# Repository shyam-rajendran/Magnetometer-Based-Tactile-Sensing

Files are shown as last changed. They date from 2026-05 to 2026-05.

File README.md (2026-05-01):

# Tactile Sensor

<table align="center">
  <tr>
    <td></td>
    <td></td>
    <td></td>
    <td></td>
  </tr>
</table>

This tactile sensor utilizes magnetometers as a means to detect force vectors acting on the surface. This is done through the combination of magnetometers and a silicone elastomer embedded with neodymium magnets.

This project is heavily inspired by the work of [AnySkin](https://any-skin.github.io/), [ReSkin](https://reskin.dev/) & [Bio-Skin](https://williamalexanda.github.io/Bio-Skin/) and the project is intended to be further developed for magnetic localization, which as of now is still in development. 

The PCB was designed entirely in Altium Designer. I've included the entire Altium project file including the design files, libraries, 3D models, documentations, schematics, gerber.

## Repo Structure
```
1. CAD Files (folder) - Contains the enclosure and mold SolidWorks Part & Assembly files
    a. Mold Designs
        - New Mold Wall 1.SLDPRT
        - New Mold Wall 2.SLDPRT
        - New Mold Assembly.SLDASM
    b. New Enclosure
        - assembly whole thing.SLDASM
        - Bottom enclosure.SLDPRT
        - initial mold assembly.SLDASM
        - Mold Top.SLDPRT
        - Top enclosure.SLDPRT

2. Docs (folder)
   Datasheets of the components used

3. Fabrication Files (folder)
   Gerber file used for manufacturing the PCB

4. Fimrware (folder)
   PlatformIO-VSCode based code environment

5. Libraries (folder) - Includes all the libraries made for PCB design within Altium
    a. 6pin jst.IntLib
    b. PcbLib1.PcbLib
    c. Schlib1.SchLib

6. PCB Design Files (folder)
    a. AnySkin.PcbDoc
    b. AnySkin.PrjPcb
    c. Interface.SchDoc
    d. Schematics.pdf
    e. Sensor Suite.SchDoc

7. Software (folder)
   Python Scripts for force visualization

```

## Sensor ICs used
- MLX90393 (6 Axis Magnetometer) 
- TMP102 (Digital Temperature Sensor)
- TCA9548 (I2C Multiplexer)
- AMS1117 (Low Dropout Voltage Regulator)

## Pinout & Address
The I2C addresses of the ICs are physically set to the specified addresses below but can be changed to alternate I2C address through hardwiring (not recommended).

All the magnetometers share the same I2C address, therefore to prevent address conflict, each magnetometer is connected to the multiplexer and has an individual assigned channel which are selected using bitwise left shift operation. 

_**I2C Peripheral Addresses**_
| Sensor  | I2C Address |
| --- |---|
| MLX90393| 0x0F |
| TMP102  | 0x48 |
| TCA9548 | 0x71 |

\
_**Multiplexer Channel Designation**_
<table>
  <tr>
    <td>

**Multiplexer Channels**
| Channel No | Sensor Address |
|---|---|
| Channel 0  | 0x0F |
| Channel 1  | 0x0F |
| Channel 2  | 0x0F |
| Channel 3  | 0x0F |
| Channel 4  | 0x0F |
| Channel 5  | 0x48 |
| Channel 6  | 0x48 |
| Channel 7  | Unassigned |

  </td>
  <td>

channel desig

  </td>
  </tr>
</table>

## Silicone Elastomer Fabrication
For this project, a two part silicone elastomer is used ([Amazon Link](https://www.amazon.in/RANA-POLYMERS-Silicone-Non-Toxic-Odorless-1/dp/B0F47XKC3K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)) which is mixed in a 1:1 ratio and is then poured into the 3D printed mold design. It roughly takes 3-4 hours for curing and can be easily taken out post curing. 

The elastomer is layered in two parts, such that an array of Neodymium magnets are sandwiched in between.  The Nd magnets are arranged in a 3X3 format such that 5 Nd magnets lie directly above the magnetometer and the remaining 4 Nd magnets lie in the interstitial space between them.

The entire process can be divided into three stages:

1. `First Elastomer Layer` 
    -  The mixture of Part A & B is poured into the mold enclosure upto 3 mm height and is then allowed to cure.
2. `Magnets Arrangement` 
    - Once the initial elastomer layer is cured, the magnets are arranged manually and are forcefully sticked onto the top surface of the first silicone layer using adhesive. 
3. `Second Elastomer Layer`
    - The second elastomer layer is poured on top of the magnets, filling out the entire remaining volume of the mold. Allow it to cure for 3-4 hours and then the mold walls can be removed.

<table align="center">
  <tr>
    <td></td>
    <td></td>
    <td></td>
  </tr>
</table>

After taking out the silicone elastomer, it can be put directly on top of the enclosure and is ready to use! 

\
Author: Shyam Rajendran

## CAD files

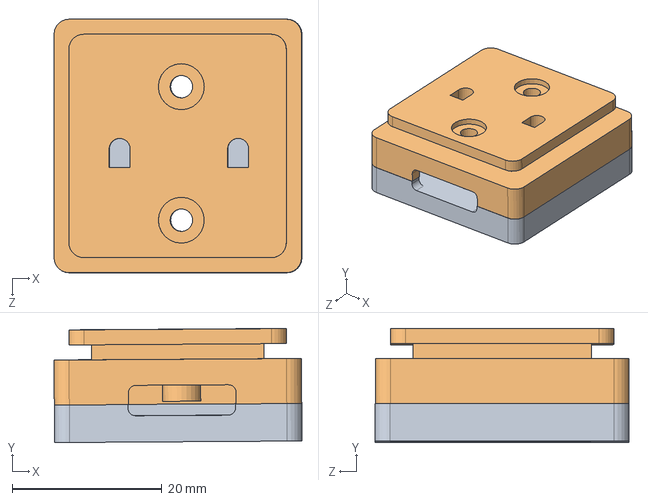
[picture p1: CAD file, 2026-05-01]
CAD Files/new enclosures/assembly whole thing.SLDASM
33.1 x 15.2 x 33.8 mm
Top enclosure
Bottom enclosure

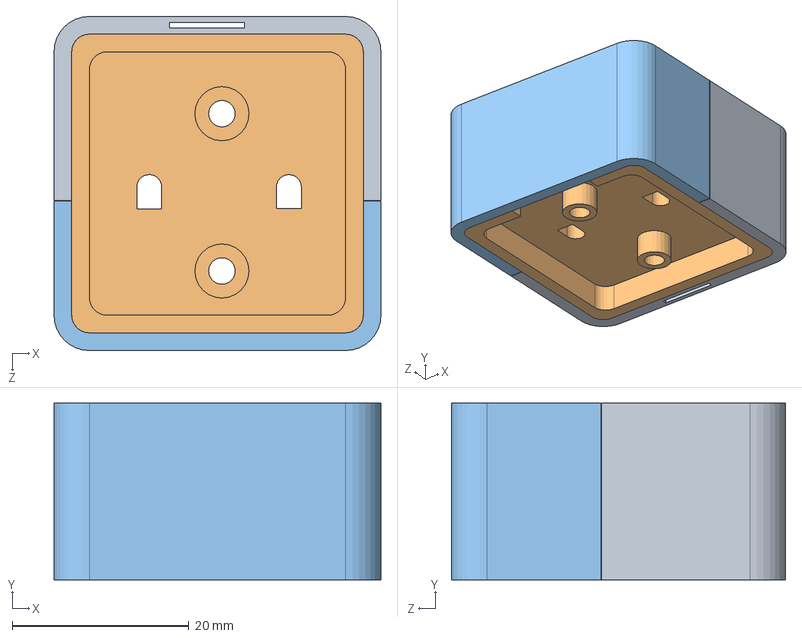
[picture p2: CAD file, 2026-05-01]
CAD Files/mold designs/NEW MOLD ASSEMBLY.SLDASM
37.0 x 20.0 x 37.8 mm
new mold wall 2
Top enclosure
New mold Wall 1

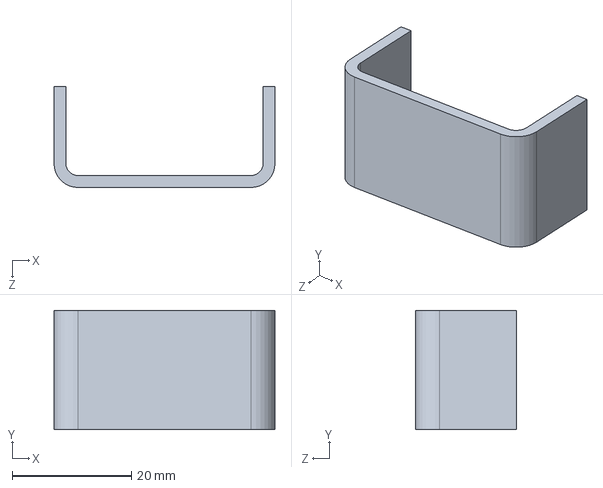
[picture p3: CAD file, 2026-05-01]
CAD Files/mold designs/new mold wall 2.SLDPRT
37.0 x 20.0 x 16.9 mm

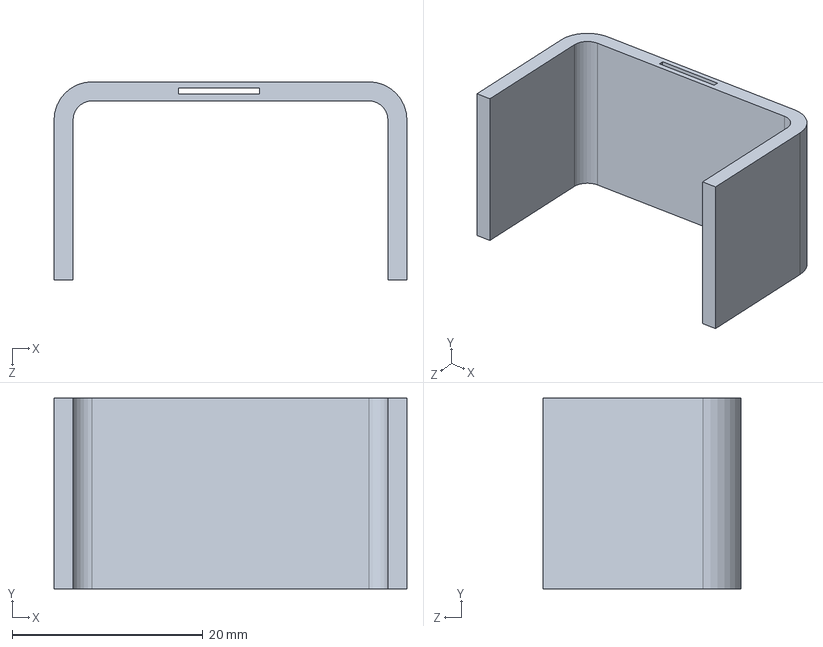
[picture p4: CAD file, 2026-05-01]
CAD Files/mold designs/New mold Wall 1.SLDPRT
37.0 x 20.0 x 20.8 mm

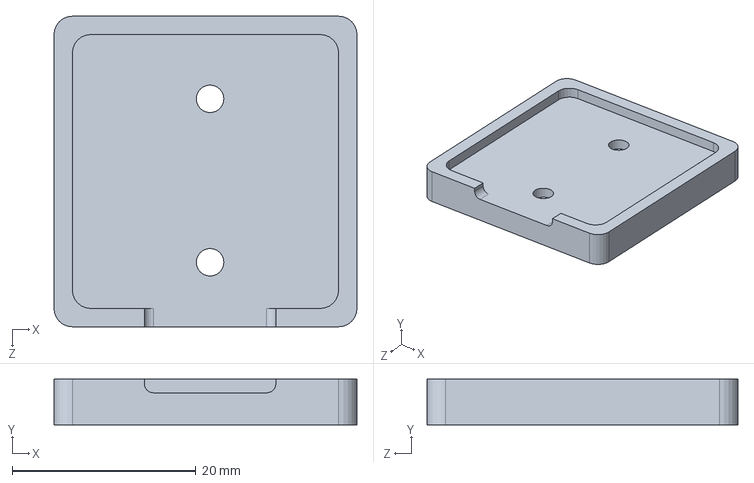
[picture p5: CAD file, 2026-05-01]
CAD Files/new enclosures/Bottom enclosure.SLDPRT
33.0 x 5.00 x 33.8 mm

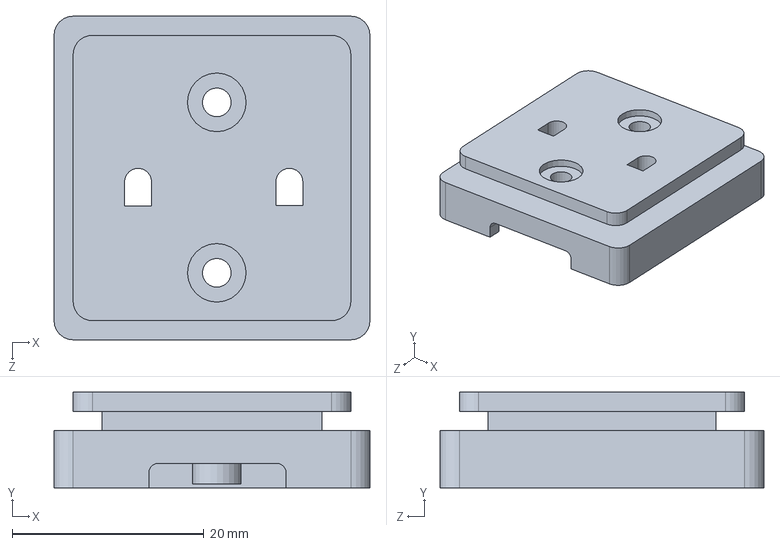
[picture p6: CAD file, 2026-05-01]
CAD Files/new enclosures/Top enclosure.SLDPRT
33.0 x 10.0 x 33.8 mm

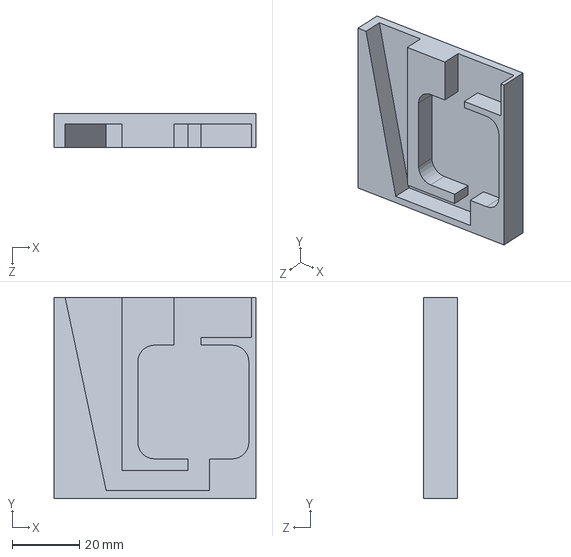
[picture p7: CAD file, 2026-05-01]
CAD Files/new enclosures/Mold Top.SLDPRT
60.0 x 59.8 x 10.0 mm

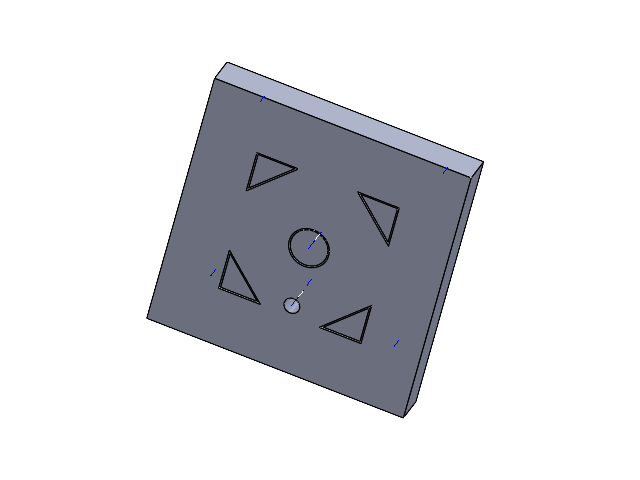
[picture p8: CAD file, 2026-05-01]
CAD Files/new enclosures/initial mold assembly.SLDASM
Mold shape
mold casing alternate bottom

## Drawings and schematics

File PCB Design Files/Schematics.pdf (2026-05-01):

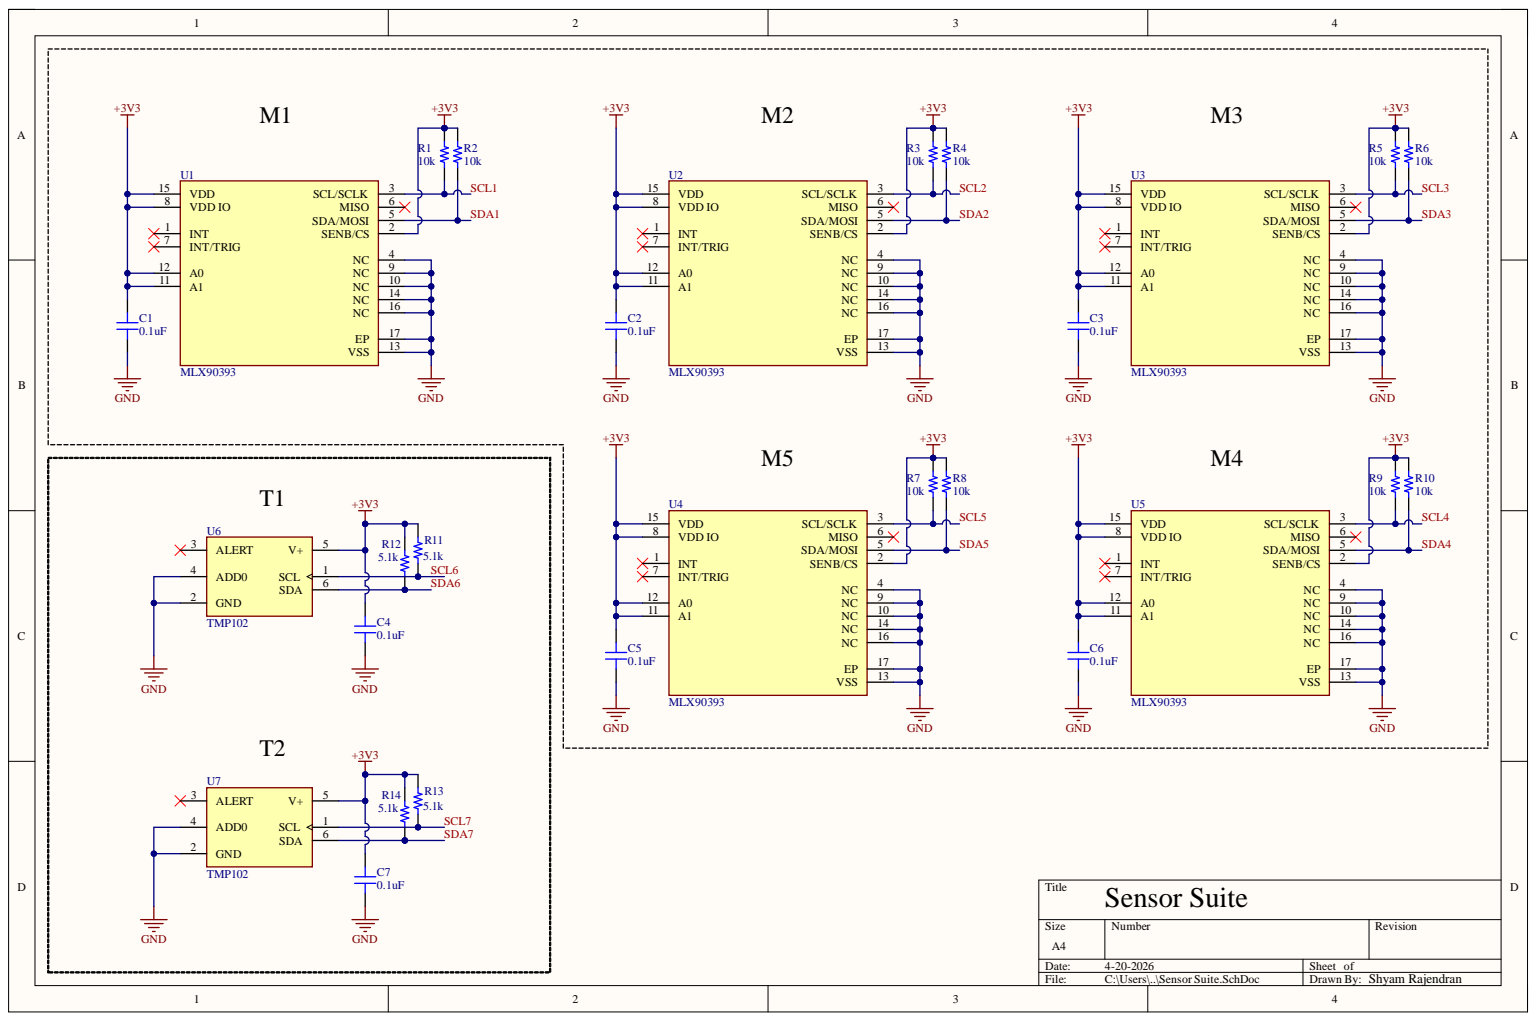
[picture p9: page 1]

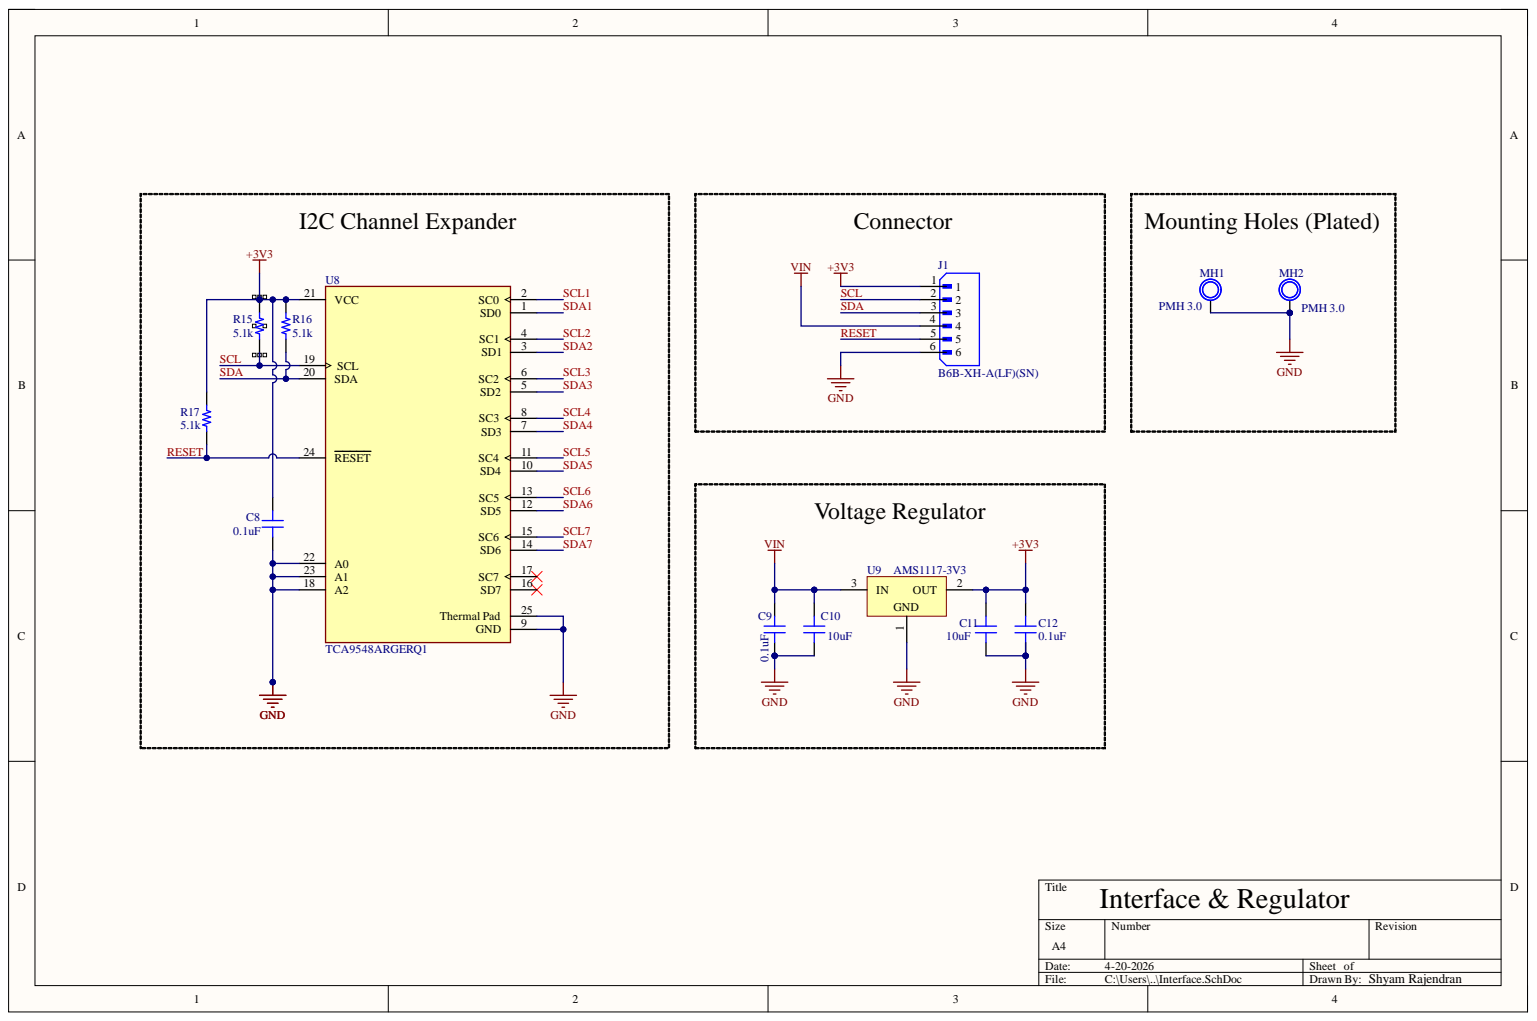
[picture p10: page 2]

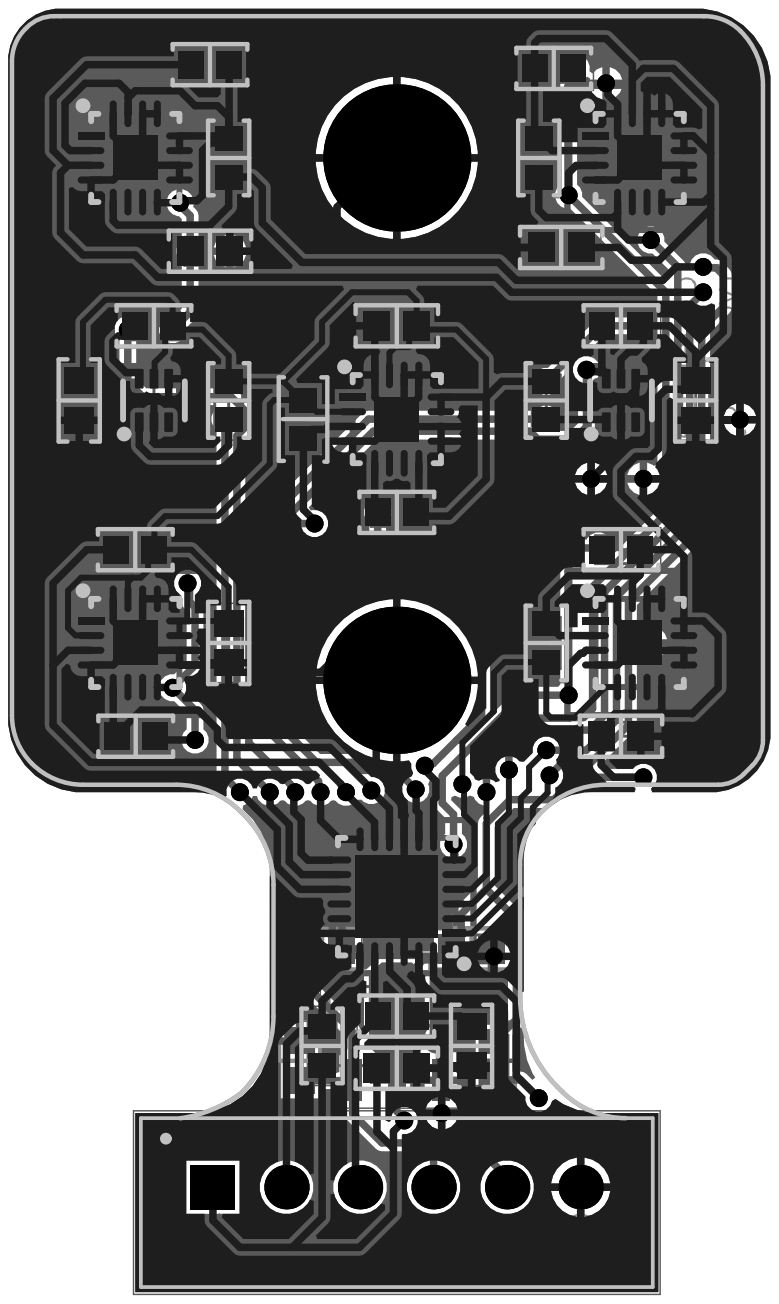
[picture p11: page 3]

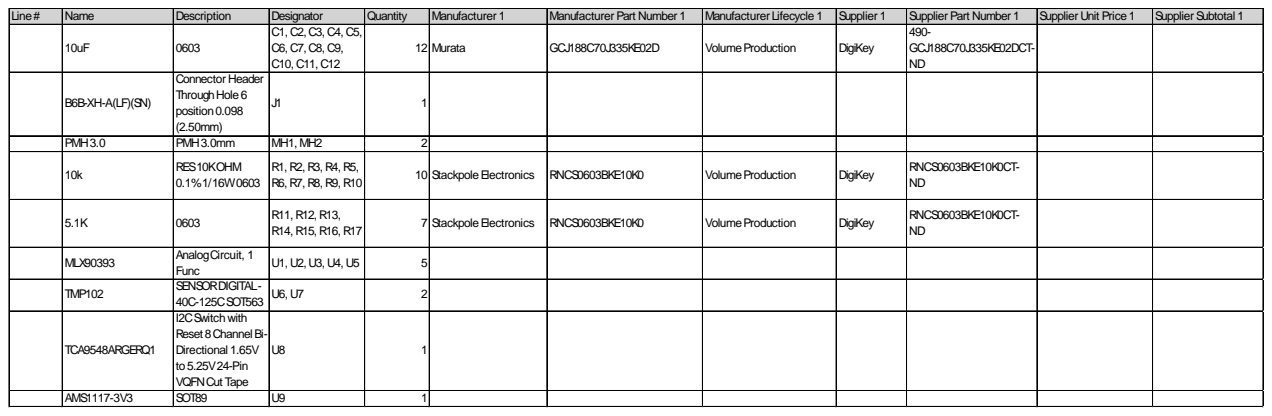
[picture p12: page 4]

Line# | Name | Description | Designator | Quantity | Manufacturer 1 | Manufacturer Part Number 1 | Manufacturer Lifecycle 1 | Supplier 1 | Supplier Part Number 1 | Supplier Unit Price 1 | Supplier Subtotal 1

10uF | 0603 | C1, C2, C3, C4, C5, C6, C7, C8, C9, C10, C11, C12 | 12 | Murata | GCJ188C70J335KE02D | VolumeProduction | DigiKey | 490-GCJ188C70J335KE02DCT-ND

B6B-XH-A(LF)(SN) | Connector Header ThroughHole6 position0.098 (2.50mm) | J1 | 1

PMH3.0 | PMH3.0mm | MH1, MH2 | 2

10k | RES10KOHM 0.1%1/16W0603 | R1, R2, R3, R4, R5, R6, R7, R8, R9, R10 | 10 | StackpoleElectronics | RNCS0603BKE10K0 | VolumeProduction | DigiKey | RNCS0603BKE10K0CT-ND

5.1K | 0603 | R11, R12, R13, R14, R15, R16, R17 | 7 | StackpoleElectronics | RNCS0603BKE10K0 | VolumeProduction | DigiKey | RNCS0603BKE10K0CT-ND

MLX90393 | AnalogCircuit, 1 Func | U1, U2, U3, U4, U5 | 5

TMP102 | SENSORDIGITAL-40C-125CSOT563 | U6, U7 | 2

TCA9548ARGERQ1 | I2CSwitch with Reset 8Channel Bi-Directional 1.65V to5.25V24-Pin VQFNCut Tape | U8 | 1

AMS1117-3V3 | SOT89 | U9 | 1

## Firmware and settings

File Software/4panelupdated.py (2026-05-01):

import sys
import numpy as np
import serial
import time
from multiprocessing import Process, Array, Value, Event
import ctypes as ct
from scipy.interpolate import griddata
from matplotlib.backends.backend_qt5agg import FigureCanvasQTAgg as FigureCanvas
from matplotlib.figure import Figure
from mpl_toolkits.mplot3d import Axes3D  # noqa: F401

from PyQt5 import QtWidgets, QtCore, QtGui
import pyqtgraph as pg

# ── Config ───────────────────────────────────────────────────────────────
PORT = 'COM5'
BAUD = 250000
NUM_SENSORS = 5

# ── Sensor layout (meters) ───────────────────────────────────────────────
SENSOR_POS = np.array([
    [0.000, 0.018],   # ch0 top-left
    [0.018, 0.018],   # ch1 top-right
    [0.018, 0.000],   # ch2 bottom-right
    [0.009, 0.009],   # ch3 center
    [0.000, 0.000],   # ch4 bottom-left
])

# ── TMP102 physical positions (meters) — adjust to match your PCB ────────
TEMP_POS = np.array([
    [0.004, 0.009],   # T1 (ch5) — left side
    [0.014, 0.009],   # T2 (ch6) — right side
])

# ── Temperature safety thresholds (°C) ──────────────────────────────────
TEMP_SAFE    = 36.0
TEMP_CAUTION = 43.0
TEMP_DANGER  = 48.0

# ── Per-sensor chip orientation (radians, CCW from +X) ───────────────────
CHIP_ROTATIONS = np.zeros(NUM_SENSORS)

# ── Per-sensor circle+arrow panel layout (pixels in 220x220 canvas) ──────
CHIP_PX = np.array([
    [ 55,  55],   # ch0 top-left
    [165,  55],   # ch1 top-right
    [165, 165],   # ch2 bottom-right
    [110, 110],   # ch3 center
    [ 55, 165],   # ch4 bottom-left
], dtype=float)

CANVAS_SIZE = 220
BZ_SCALE    = 2.0
XY_SCALE    = 2.0

# ── Adaptive EMA baseline config ─────────────────────────────────────────
EMA_ALPHA          = 0.02
ACTIVITY_THRESHOLD = 3.0
DEAD_ZONE          = 5.0

# ── Heatmap / 3D grid ────────────────────────────────────────────────────
GRID_RES = 50
xi = np.linspace(0, 0.018, GRID_RES)
yi = np.linspace(0, 0.018, GRID_RES)
XI, YI = np.meshgrid(xi, yi)

HMAP_RES = 100
xi_h = np.linspace(0, 0.018, HMAP_RES)
yi_h = np.linspace(0, 0.018, HMAP_RES)
XI_H, YI_H = np.meshgrid(xi_h, yi_h)


# ── Parse ─────────────────────────────────────────────────────────────────
def parse_line(line):
    data  = np.zeros((NUM_SENSORS, 3))
    temps = [None, None]
    try:
        tokens = line.strip().split(',')
        i = 0
        while i < len(tokens):
            tok = tokens[i].strip()
            if tok.startswith('#'):
                ch = int(tok[1:])
                if ch < NUM_SENSORS and i + 3 < len(tokens):
                    data[ch] = [float(tokens[i+1]), float(tokens[i+2]), float(tokens[i+3])]
                i += 4
            elif tok == 'T1':
                temps[0] = float(tokens[i+1])
                i += 2
            elif tok == 'T2':
                temps[1] = float(tokens[i+1])
                i += 2
            else:
                i += 1
        return data, temps
    except Exception:
        return None, [None, None]


# ── Background serial reader process ─────────────────────────────────────
class SensorProcess(Process):
    def __init__(self):
        super().__init__(daemon=True)
        self._raw       = Array(ct.c_float, NUM_SENSORS * 3)
        self._baseline  = Array(ct.c_float, NUM_SENSORS * 3)
        self._counter   = Value(ct.c_uint64, 0)
        self._ready     = Event()
        self._recal_req = Event()
        self._temps     = Array(ct.c_float, 2)
        self._temps[0]  = -999.0
        self._temps[1]  = -999.0

        self.CONTACT_THRESHOLD = 3.5

    @property
    def counter(self):
        return self._counter.value

    @property
    def latest(self):
        raw      = np.array(self._raw[:]).reshape(NUM_SENSORS, 3)
        baseline = np.array(self._baseline[:]).reshape(NUM_SENSORS, 3)
        delta    = raw - baseline
        mean     = np.mean(delta, axis=0)
        delta    = delta - mean
        delta[np.abs(delta) < DEAD_ZONE] = 0.0
        return delta

    @property
    def temperatures(self):
        return list(self._temps)

    def request_recalibrate(self):
        self._recal_req.set()

    def wait_until_ready(self, timeout=20.0):
        return self._ready.wait(timeout=timeout)

    def _read_sample(self, ser):
        if ser.in_waiting > 4000:
            ser.reset_input_buffer()
            ser.readline()
        raw = ser.readline().decode('utf-8', errors='ignore')
        return parse_line(raw)

    def _hard_baseline(self, ser, n=30):
        print("[SensorProcess] Capturing baseline — keep sensor still...")
        samples = []
        while len(samples) < n:
            data, _ = self._read_sample(ser)
            if data is not None:
                samples.append(data)
        baseline = np.mean(samples, axis=0)
        self._baseline[:] = baseline.flatten().tolist()
        print("[SensorProcess] Baseline done.")
        return baseline.copy()

    def run(self):
        ser = serial.Serial(PORT, BAUD, timeout=1)
        print(f"[SensorProcess] Connected to {PORT}")
        time.sleep(2.0)
        ser.reset_input_buffer()

        baseline = self._hard_baseline(ser)
        self._ready.set()

        while True:
            if self._recal_req.is_set():
                self._recal_req.clear()
                baseline = self._hard_baseline(ser)

            data, temps = self._read_sample(ser)
            if data is None:
                continue

            self._raw[:] = data.flatten().tolist()
            self._counter.value += 1

            if temps[0] is not None:
                self._temps[0] = temps[0]
            if temps[1] is not None:
                self._temps[1] = temps[1]

            delta = data - baseline
            mean  = np.mean(delta, axis=0)
            delta_cm_removed  = delta - mean
            spatial_variation = np.std(delta_cm_removed, axis=0)
            variation_norm    = np.linalg.norm(spatial_variation)
            is_contact        = variation_norm > self.CONTACT_THRESHOLD

            if not is_contact:
                baseline = (1.0 - EMA_ALPHA) * baseline + EMA_ALPHA * data
                self._baseline[:] = baseline.flatten().tolist()


# ── Per-sensor circle+arrow widget ───────────────────────────────────────
class SensorDotWidget(QtWidgets.QWidget):
    def __init__(self, parent=None):
        super().__init__(parent)
        self.setMinimumSize(300, 300)
        self.setSizePolicy(QtWidgets.QSizePolicy.Expanding, QtWidgets.QSizePolicy.Expanding)
        self._data = np.zeros((NUM_SENSORS, 3))

        self._rot = []
        for angle in CHIP_ROTATIONS:
            c, s = np.cos(angle), np.sin(angle)
            self._rot.append(np.array([[c, -s], [s, c]]))

    def update_data(self, data):
        self._data = data
        self.update()

    def paintEvent(self, event):
        painter = QtGui.QPainter(self)
        painter.setRenderHint(QtGui.QPainter.Antialiasing)
        painter.fillRect(self.rect(), QtGui.QColor('#1a1a2e'))

        side     = min(self.width(), self.height())
        x_offset = (self.width()  - side) / 2.0
        y_offset = (self.height() - side) / 2.0
        scale    = side / CANVAS_SIZE
        painter.translate(x_offset, y_offset)
        painter.scale(scale, scale)

        painter.setPen(QtGui.QPen(QtGui.QColor(80, 80, 120), 1))
        for px in CHIP_PX:
            painter.drawEllipse(int(px[0]) - 2, int(px[1]) - 2, 4, 4)

        for i, px in enumerate(CHIP_PX):
            bx, by, bz = self._data[i]
            radius = max(int(abs(bz) / BZ_SCALE), 1)
            cx, cy = int(px[0]), int(px[1])

            if bz >= 0:
                painter.setBrush(QtGui.QBrush(QtGui.QColor(220, 60, 60)))
                painter.setPen(QtGui.QPen(QtGui.QColor(220, 60, 60)))
            else:
                painter.setBrush(QtGui.QBrush(QtCore.Qt.NoBrush))
                painter.setPen(QtGui.QPen(QtGui.QColor(220, 60, 60), 2))
            painter.drawEllipse(cx - radius, cy - radius, radius * 2, radius * 2)

            xy_raw = np.array([bx, -by])
            xy_rot = self._rot[i] @ xy_raw
            ax = cx + xy_rot[0] / XY_SCALE
            ay = cy + xy_rot[1] / XY_SCALE

            painter.setPen(QtGui.QPen(QtGui.QColor(46, 204, 113), 2))
            painter.drawLine(cx, cy, int(ax), int(ay))

            length = np.hypot(xy_rot[0], xy_rot[1]) / XY_SCALE
            if length > 3:
                angle = np.arctan2(xy_rot[1], xy_rot[0])
                head  = 6
                for side in [0.4, -0.4]:
                    hx = ax - head * np.cos(angle + side)
                    hy = ay - head * np.sin(angle + side)
                    painter.drawLine(int(ax), int(ay), int(hx), int(hy))

            painter.setPen(QtGui.QPen(QtGui.QColor(200, 200, 200)))
            painter.drawText(cx + radius + 3, cy - radius, f"CH{i}")

        painter.end()


# ── 3D surface widget ─────────────────────────────────────────────────────
class MatplotlibSurfaceWidget(FigureCanvas):
    def __init__(self, parent=None):
        self.figure = Figure(facecolor='#1a1a2e')
        super().__init__(self.figure)
        if parent is not None:
            self.setParent(parent)

        self.setMinimumSize(300, 300)
        self.setSizePolicy(QtWidgets.QSizePolicy.Expanding, QtWidgets.QSizePolicy.Expanding)

        self.ax = self.figure.add_subplot(111, projection='3d')
        self.ax.set_facecolor('#1a1a2e')
        self.ax.view_init(elev=35, azim=-135)
        self.figure.subplots_adjust(left=0.02, right=0.98, bottom=0.05, top=0.95)

        self._surface       = None
        self._sensor_points = None
        self._configure_axes()
        self.update_surface(np.zeros(NUM_SENSORS))

    def _configure_axes(self):
        self.ax.set_title("3D Force Surface (Bz)", color='white', pad=12)
        self.ax.set_xlabel("X (mm)", color='white', labelpad=8)
        self.ax.set_ylabel("Y (mm)", color='white', labelpad=8)
        self.ax.set_zlabel("Bz (uT)", color='white', labelpad=6)
        self.ax.set_xlim(0, 18)
        self.ax.set_ylim(0, 18)
        self.ax.set_zlim(-100, 0)
        self.ax.tick_params(colors='white')
        self.ax.xaxis.pane.set_facecolor((0.10, 0.10, 0.18, 1.0))
        self.ax.yaxis.pane.set_facecolor((0.10, 0.10, 0.18, 1.0))
        self.ax.zaxis.pane.set_facecolor((0.10, 0.10, 0.18, 1.0))

    def update_surface(self, bz_sensors):
        zi = griddata(SENSOR_POS, bz_sensors, (XI_H, YI_H), method='cubic', fill_value=0)
        zi = np.clip(zi, 0, None)
        zi = -zi   # invert so touch pushes DOWN

        if self._surface is not None:
            self._surface.remove()
        if self._sensor_points is not None:
            self._sensor_points.remove()

        x_mm = XI_H * 1000.0
        y_mm = YI_H * 1000.0
        z_uT = zi
        vmax = max(float(np.max(np.abs(z_uT))), 1.0)

        self.ax.set_zlim(-max(vmax * 1.1, 10.0), 0)
        self._surface = self.ax.plot_surface(
            x_mm, y_mm, z_uT,
            cmap='turbo_r',
            linewidth=0,
            antialiased=True,
            vmin=-max(vmax, 10.0),
            vmax=0,
        )
        self._sensor_points = self.ax.scatter(
            SENSOR_POS[:, 0] * 1000.0,
            SENSOR_POS[:, 1] * 1000.0,
            -np.clip(bz_sensors, 0, None),
            c='white', s=18, depthshade=False,
        )
        self.draw_idle()


# ── Temperature heatmap widget ────────────────────────────────────────────
class TempHeatmapWidget(pg.GraphicsLayoutWidget):
    def __init__(self, parent=None):
        super().__init__(parent)
        self.setMinimumSize(300, 300)

        self.plot = self.addPlot(title="Temperature Heatmap (°C)")
        self.plot.setLabel('left', 'Y (mm)')
        self.plot.setLabel('bottom', 'X (mm)')
        self.plot.setAspectLocked(True)

        self.img = pg.ImageItem()
        self.plot.addItem(self.img)
        self.img.setRect(pg.QtCore.QRectF(0, 0, 18, 18))

        # Blue (cold) → green (safe) → yellow (caution) → red (danger)
        # Mapped across 20–50 °C range
        colors = [
            (0,   80,  200),   # cold blue   ~20°C
            (0,   200, 100),   # safe green  ~36°C
            (255, 200, 0  ),   # caution     ~43°C
            (220, 40,  40 ),   # danger red  ~48°C+
        ]
        # Normalise threshold positions to [0,1] over 20–50°C
        TMIN, TMAX = 20.0, 50.0
        pos = np.array([
            0.0,
            (TEMP_SAFE    - TMIN) / (TMAX - TMIN),
            (TEMP_CAUTION - TMIN) / (TMAX - TMIN),
            1.0,
        ])
        cmap = pg.ColorMap(pos=pos, color=colors)
        self.colorbar = pg.ColorBarItem(
            values=(TMIN, TMAX), colorMap=cmap, label='°C'
        )
        self.colorbar.setImageItem(self.img, insert_in=self.plot)

        # Sensor position markers (triangles)
        temp_mm = TEMP_POS * 1000
        self.plot.plot(
            temp_mm[:, 0], temp_mm[:, 1],
            pen=None, symbol='t', symbolSize=12,
            symbolBrush='w', symbolPen='w'
        )

        # Readout labels for T1 and T2
        self._t1_label = pg.TextItem("T1: --.-°C", color='white', anchor=(0, 1))
        self._t2_label = pg.TextItem("T2: --.-°C", color='white', anchor=(1, 1))
        self._t1_label.setPos(0,   18)
        self._t2_label.setPos(18,  18)
        self.plot.addItem(self._t1_label)
        self.plot.addItem(self._t2_label)

        self._last_temps = [25.0, 25.0]
        self.TMIN = TMIN
        self.TMAX = TMAX

    def _temp_color(self, t):
        """Return a hex color string for a temperature value."""
        if t < TEMP_SAFE:
            return '#2ecc71'
        elif t < TEMP_CAUTION:
            return '#f39c12'
        else:
            return '#e74c3c'

    def update_temps(self, temps):
        t = [
            temps[i] if (temps[i] is not None and temps[i] > -900)
            else self._last_temps[i]
            for i in range(2)
        ]
        self._last_temps = t

        # Interpolate temperature across full 18×18 mm grid
        zi = griddata(TEMP_POS, np.array(t), (XI_H, YI_H),
                      method='linear', fill_value=float(np.mean(t)))

        # Normalise to [0, 1] for the colormap (20–50°C)
        zi_norm = (zi - self.TMIN) / (self.TMAX - self.TMIN)
        zi_norm = np.clip(zi_norm, 0, 1)

        self.img.setImage(zi_norm.T)
        self.colorbar.setLevels((self.TMIN, self.TMAX))

        # Update readout text with safety colour
        self._t1_label.setText(f"T1: {t[0]:.1f}°C")
        self._t2_label.setText(f"T2: {t[1]:.1f}°C")
        self._t1_label.setColor(self._temp_color(t[0]))
        self._t2_label.setColor(self._temp_color(t[1]))


# ── Main window ───────────────────────────────────────────────────────────
class Visualizer(QtWidgets.QMainWindow):
    def __init__(self, sensor: SensorProcess):
        super().__init__()
        self.sensor        = sensor
        self._last_counter = -1

        self.setWindowTitle("Tactile Sensor Visualizer  |  B = recalibrate baseline")
        self.resize(1200, 900)

        pg.setConfigOption('background', '#1a1a2e')
        pg.setConfigOption('foreground', 'w')

        central = QtWidgets.QWidget()
        self.setCentralWidget(central)
        layout = QtWidgets.QGridLayout(central)
        layout.setSpacing(10)
        layout.setContentsMargins(10, 10, 10, 10)
        layout.setRowStretch(0, 1)
        layout.setRowStretch(1, 1)
        layout.setColumnStretch(0, 1)
        layout.setColumnStretch(1, 1)

        # ── Panel 0,0: Bz Heatmap ────────────────────────────────────────
        self.heatmap_widget = pg.GraphicsLayoutWidget()
        layout.addWidget(self.heatmap_widget, 0, 0)

        self.heat_plot = self.heatmap_widget.addPlot(title="Bz Heatmap")
        self.heat_plot.setLabel('left', 'Y (mm)')
        self.heat_plot.setLabel('bottom', 'X (mm)')
        self.heat_plot.setAspectLocked(True)

        self.img_item = pg.ImageItem()
        self.heat_plot.addItem(self.img_item)
        self.img_item.setRect(pg.QtCore.QRectF(0, 0, 18, 18))

        colormap = pg.colormap.get('RdBu_r', source='matplotlib')
        self.colorbar = pg.ColorBarItem(values=(-100, 100), colorMap=colormap, label='Bz (uT)')
        self.colorbar.setImageItem(self.img_item, insert_in=self.heat_plot)

        sensor_mm = SENSOR_POS * 1000
        self.heat_plot.plot(
            sensor_mm[:, 0], sensor_mm[:, 1],
            pen=None, symbol='x', symbolSize=10,
            symbolBrush='w', symbolPen='w'
        )

        # ── Panel 0,1: Bar charts ─────────────────────────────────────────
        self.bar_widget = pg.GraphicsLayoutWidget()
        layout.addWidget(self.bar_widget, 0, 1)

        self.bar_plot = self.bar_widget.addPlot(title="Per-Sensor Field (uT)")
        self.bar_plot.setLabel('left', 'uT')
        self.bar_plot.setLabel('bottom', 'Sensor Channel')
        self.bar_plot.addLegend(offset=(10, 10))
        self.bar_plot.showGrid(y=True, alpha=0.3)

        x = np.arange(NUM_SENSORS)
        w = 0.25
        self.bars_bx = self._make_bars(x - w, w, '#e74c3c', 'Bx')
        self.bars_by = self._make_bars(x,     w, '#2ecc71', 'By')
        self.bars_bz = self._make_bars(x + w, w, '#3498db', 'Bz')

        ticks = [[(i, f'CH{i}') for i in range(NUM_SENSORS)]]
        self.bar_plot.getAxis('bottom').setTicks(ticks)
        self.bar_plot.setYRange(-200, 200)

        # ── Panel 1,0: Temperature heatmap ───────────────────────────────
        self.temp_widget = TempHeatmapWidget()
        layout.addWidget(self.temp_widget, 1, 0)

        # ── Panel 1,1: 3D surface ─────────────────────────────────────────
        surf_container = QtWidgets.QWidget()
        surf_layout    = QtWidgets.QVBoxLayout(surf_container)
        surf_layout.setContentsMargins(8, 8, 8, 8)
        surf_layout.setSpacing(6)

        surf_title = QtWidgets.QLabel("3D Force Surface (Bz)")
        surf_title.setAlignment(QtCore.Qt.AlignCenter)
        surf_title.setStyleSheet("color: white; font-size: 11px;")
        surf_layout.addWidget(surf_title)

        self.surface_widget = MatplotlibSurfaceWidget()
        surf_layout.addWidget(self.surface_widget)

        surf_legend = QtWidgets.QLabel(
            "turbo_r colormap = Bz intensity    white dots = sensor positions")
        surf_legend.setAlignment(QtCore.Qt.AlignCenter)
        surf_legend.setStyleSheet("color: #aaaaaa; font-size: 9px;")
        surf_layout.addWidget(surf_legend)
        surf_layout.setStretch(1, 1)
        surf_container.setSizePolicy(
            QtWidgets.QSizePolicy.Expanding, QtWidgets.QSizePolicy.Expanding)

        layout.addWidget(surf_container, 1, 1)

        # ── Status bar ────────────────────────────────────────────────────
        self.statusBar().showMessage(
            "Ready  |  B = hard recalibrate  |  EMA adapts at rest  |  drag 3D panel to rotate")

        # ── Timer ─────────────────────────────────────────────────────────
        self.timer = QtCore.QTimer()
        self.timer.timeout.connect(self._update)
        self.timer.start(30)

    def _make_bars(self, x_positions, width, color, name):
        bars = []
        for i, xp in enumerate(x_positions):
            item = pg.BarGraphItem(
                x=[xp], height=[0], width=width, brush=color,
                name=name if i == 0 else None)
            self.bar_plot.addItem(item)
            bars.append(item)
        return bars

    def keyPressEvent(self, event):
        if event.key() == QtCore.Qt.Key_B:
            self.sensor.request_recalibrate()
            self.statusBar().showMessage("Recalibrating — keep sensor still...")
            QtCore.QTimer.singleShot(3000, lambda: self.statusBar().showMessage(
                "Baseline recaptured  |  EMA adapting  |  B = recalibrate again"))

    def _update(self):
        current = self.sensor.counter
        if current == self._last_counter:
            return
        self._last_counter = current

        data = self.sensor.latest   # (5,3) baseline-subtracted + dead-zoned

        # ── Bz heatmap ───────────────────────────────────────────────────
        bz   = data[:, 2]
        zi_h = griddata(SENSOR_POS, bz, (XI_H, YI_H), method='cubic', fill_value=0)
        self.img_item.setImage(zi_h.T)
        lim = max(float(np.abs(bz).max()), 1.0)
        self.colorbar.setLevels((-lim, lim))

        # ── Bar charts ────────────────────────────────────────────────────
        for i in range(NUM_SENSORS):
            self.bars_bx[i].setOpts(height=data[i, 0])
            self.bars_by[i].setOpts(height=data[i, 1])
            self.bars_bz[i].setOpts(height=data[i, 2])
        y_lim = max(float(np.abs(data).max()) * 1.2, 10.0)
        self.bar_plot.setYRange(-y_lim, y_lim)

        # ── 3D surface ────────────────────────────────────────────────────
        self.surface_widget.update_surface(bz)

        # ── Temperature heatmap ───────────────────────────────────────────
        self.temp_widget.update_temps(self.sensor.temperatures)

    def closeEvent(self, event):
        self.timer.stop()
        self.sensor.terminate()
        event.accept()


def main():
    sensor = SensorProcess()
    sensor.start()
    print("Waiting for sensor to be ready...")
    if not sensor.wait_until_ready(timeout=20.0):
        print("ERROR: Sensor did not become ready in time.")
        sensor.terminate()
        sys.exit(1)

    app = QtWidgets.QApplication(sys.argv)
    win = Visualizer(sensor)
    win.show()
    sys.exit(app.exec_())


if __name__ == '__main__':
    main()

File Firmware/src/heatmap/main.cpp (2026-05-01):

#include <Arduino.h>
#include <Wire.h>

#define SDA_PIN     15
#define SCL_PIN     2
#define TCA_ADDR    0x70
#define MLX_ADDR    0x0F
#define NUM_SENSORS 5

void tcaSelect(uint8_t channel) {
    Wire.beginTransmission(TCA_ADDR);
    Wire.write(1 << channel);
    Wire.endTransmission();
    delay(5);
}

void tcaDisableAll() {
    Wire.beginTransmission(TCA_ADDR);
    Wire.write(0x00);
    Wire.endTransmission();
}

bool mlxInit() {
    Wire.beginTransmission(MLX_ADDR);
    Wire.write(0x80);  // EX
    Wire.endTransmission();
    delay(20);

    Wire.beginTransmission(MLX_ADDR);
    Wire.write(0xF0);  // RT
    Wire.endTransmission();
    delay(20);

    // NOP to confirm alive
    Wire.beginTransmission(MLX_ADDR);
    Wire.write(0x00);
    Wire.endTransmission();
    delay(10);

    Wire.requestFrom((uint8_t)MLX_ADDR, (uint8_t)1);
    if (!Wire.available()) return false;
    Wire.read();
    return true;
}

bool mlxRead(float &Bx, float &By, float &Bz) {
    // Send SM, read status byte back in same transaction
    Wire.beginTransmission(MLX_ADDR);
    Wire.write(0x3E);  // SM XYZ
    Wire.endTransmission();
    delay(20);  // wait for conversion

    // Read 7 bytes directly — RM is implied after SM on MLX90393
    // when you requestFrom without sending RM first
    Wire.requestFrom((uint8_t)MLX_ADDR, (uint8_t)7);
    
    unsigned long t = millis();
    while (Wire.available() < 7) {
        if (millis() - t > 100) {
            Serial.printf("  timeout, got %d bytes\n", Wire.available());
            return false;
        }
    }

    uint8_t status = Wire.read();
    Serial.printf("  status=0x%02X ", status);

    int16_t rawX = (Wire.read() << 8) | Wire.read();
    int16_t rawY = (Wire.read() << 8) | Wire.read();
    int16_t rawZ = (Wire.read() << 8) | Wire.read();

    Bx = rawX * 0.15f;
    By = rawY * 0.15f;
    Bz = rawZ * 0.15f;

    return true;
}

void setup() {
    Serial.begin(115200);
    Wire.begin(SDA_PIN, SCL_PIN);
    Wire.setClock(100000);
    delay(500);

    Serial.println("Initializing sensors...");
    for (int ch = 0; ch < NUM_SENSORS; ch++) {
        tcaSelect(ch);
        if (mlxInit()) {
            Serial.printf("ch%d: OK\n", ch);
        } else {
            Serial.printf("ch%d: FAILED\n", ch);
        }
        tcaDisableAll();
        delay(20);
    }
    Serial.println("Ready");
}

void loop() {
    float Bx, By, Bz;

    for (int ch = 0; ch < NUM_SENSORS; ch++) {
        tcaSelect(ch);
        Serial.printf("ch%d:", ch);

        if (mlxRead(Bx, By, Bz)) {
            Serial.printf("Bx=%.2f By=%.2f Bz=%.2f\n", Bx, By, Bz);
        } else {
            Serial.println("FAILED");
        }

        tcaDisableAll();
        delay(5);
    }

    Serial.println("---");
    delay(200);
}
